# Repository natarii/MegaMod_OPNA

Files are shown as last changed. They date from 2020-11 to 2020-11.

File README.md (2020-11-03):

# OPNA MegaMod
This add-on board lets you play OPNA, OPN, and AY-3-8910 VGM files using your MegaGRRL Desktop.

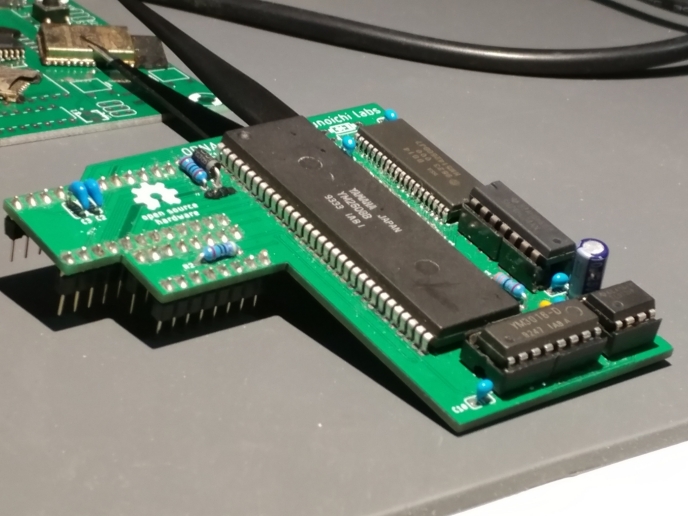
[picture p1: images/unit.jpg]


**This board is provided as an experimental add-on. Software support is working, but incomplete. Software support may improve in the future.**

**MegaGRRL Desktop Firmware v0.97dev or newer is required!** See [Firmware Releases](https://git.agiri.ninja/natalie/megagrrl/-/releases)

# Usage
1. Power off the MegaGRRL Desktop.
2. Remove the YM2612 and SN76489, and seat the addon board into their sockets.
3. Set all 4 DIP switches on the desktop board to OFF.
4. Power on. The presence of the OPNA board will be detected upon boot. Play an OPNA/OPN/AY-3-8910 VGM file.

# Bill of Materials
| Ref.Dsg. | Value | Note |
| --- | ----- | ---- |
| C1 | 10uF electrolytic |
| C2 | 2.7nF ceramic |
| C3 | 2.7nF ceramic |
| C4 | 68pF ceramic |
| C5 | 0.1uF ceramic |
| C6 | 0.1uF ceramic |
| C7 | 0.1uF ceramic |
| C8 | 0.1uF ceramic |
| C9 | 0.1uF ceramic |
| R1 | 33 ohm |
| R2 | 470 ohm |
| R3 | 1k ohm |
| RN1 | 10k bussed | Must be 9-pin bussed type |
| IC1 | YM2608 |
| IC2 | HM514260DJ | Tested with HM514260DJ. Other DRAMs may be compatible. Must be SOJ-40 footprint, 5V, 4Mbit (256Kx16), "fast page" type |
| IC3 | 74HC04 |
| IC4 | TL072 or SA5532 | Many opamps will work |
| IC5 | YM3016 |
| D1 | 1N5819 |
| Misc | 40 pins 0.1" machine pin header | 0.1" machine pin male-to-male headers, 40 pins total required. Must be machine pin type!!! |

All parts other than the DRAM at IC2 are THT.

# Assembly
1. Solder on the DRAM. Be careful to not short any pins underneath the IC
2. Solder on the remaining THT components. Pay attention that RN1 pin 1 goes towards the top of the board.
3. Solder on the pin headers (use MegaGRRL Desktop IC sockets for alignment)

# Gerber files
Gerbers for JLCPCB are in the `gerbers/` directory.

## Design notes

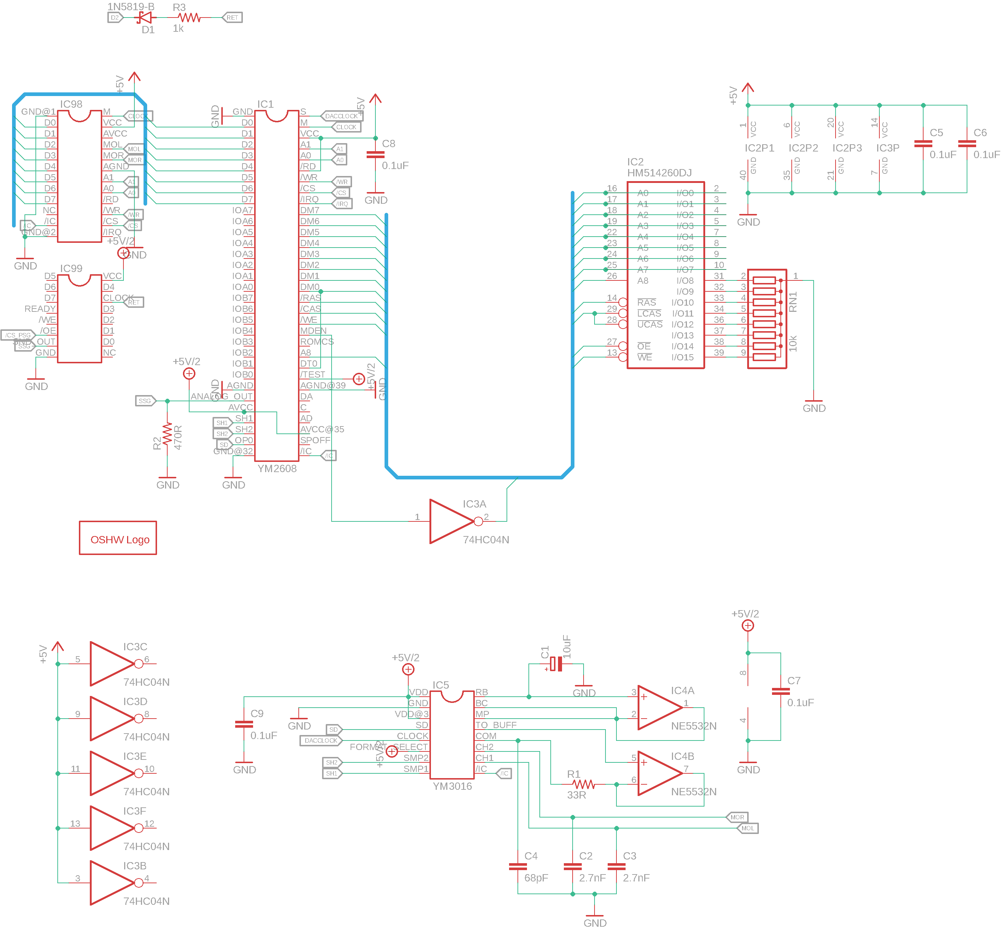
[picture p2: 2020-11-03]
images/sch.png

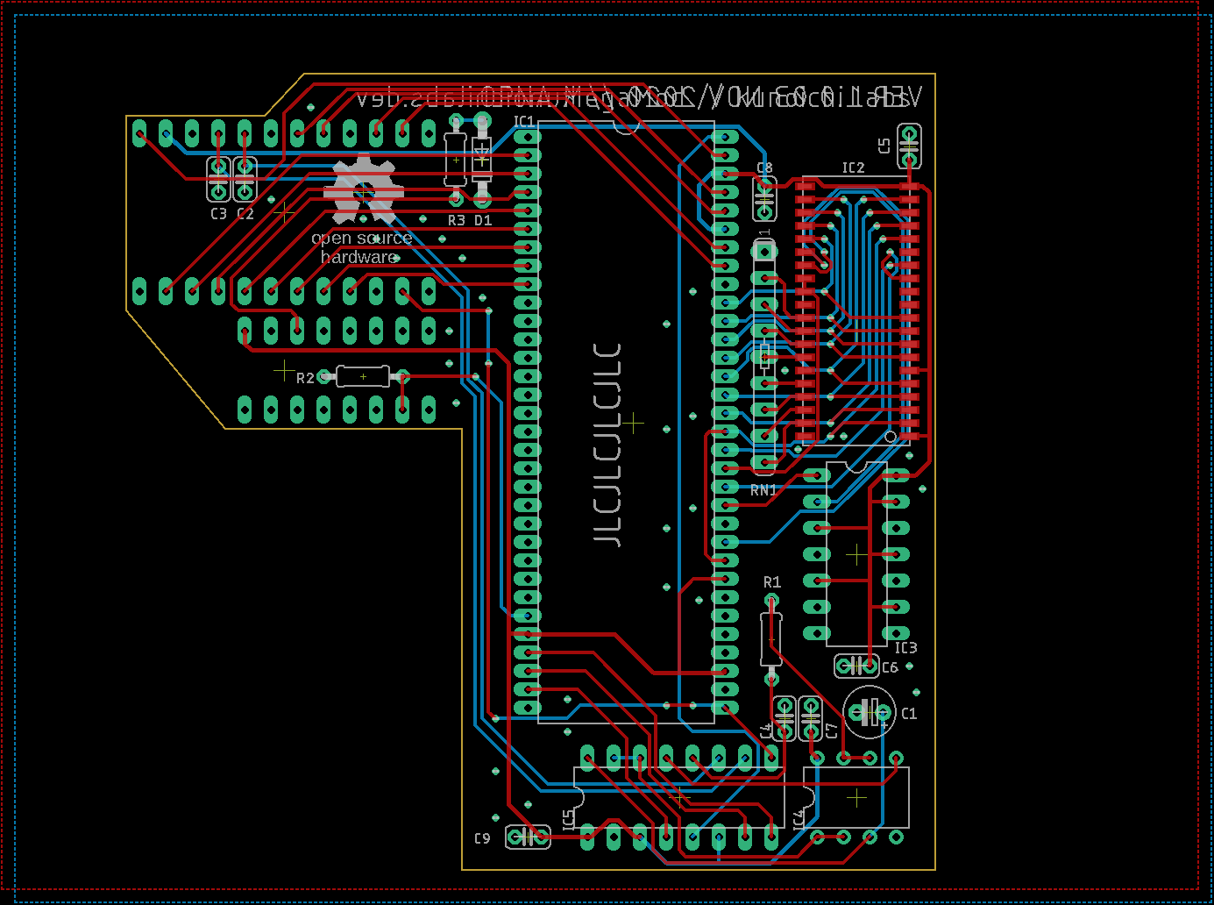
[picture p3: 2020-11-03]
images/pcb.png

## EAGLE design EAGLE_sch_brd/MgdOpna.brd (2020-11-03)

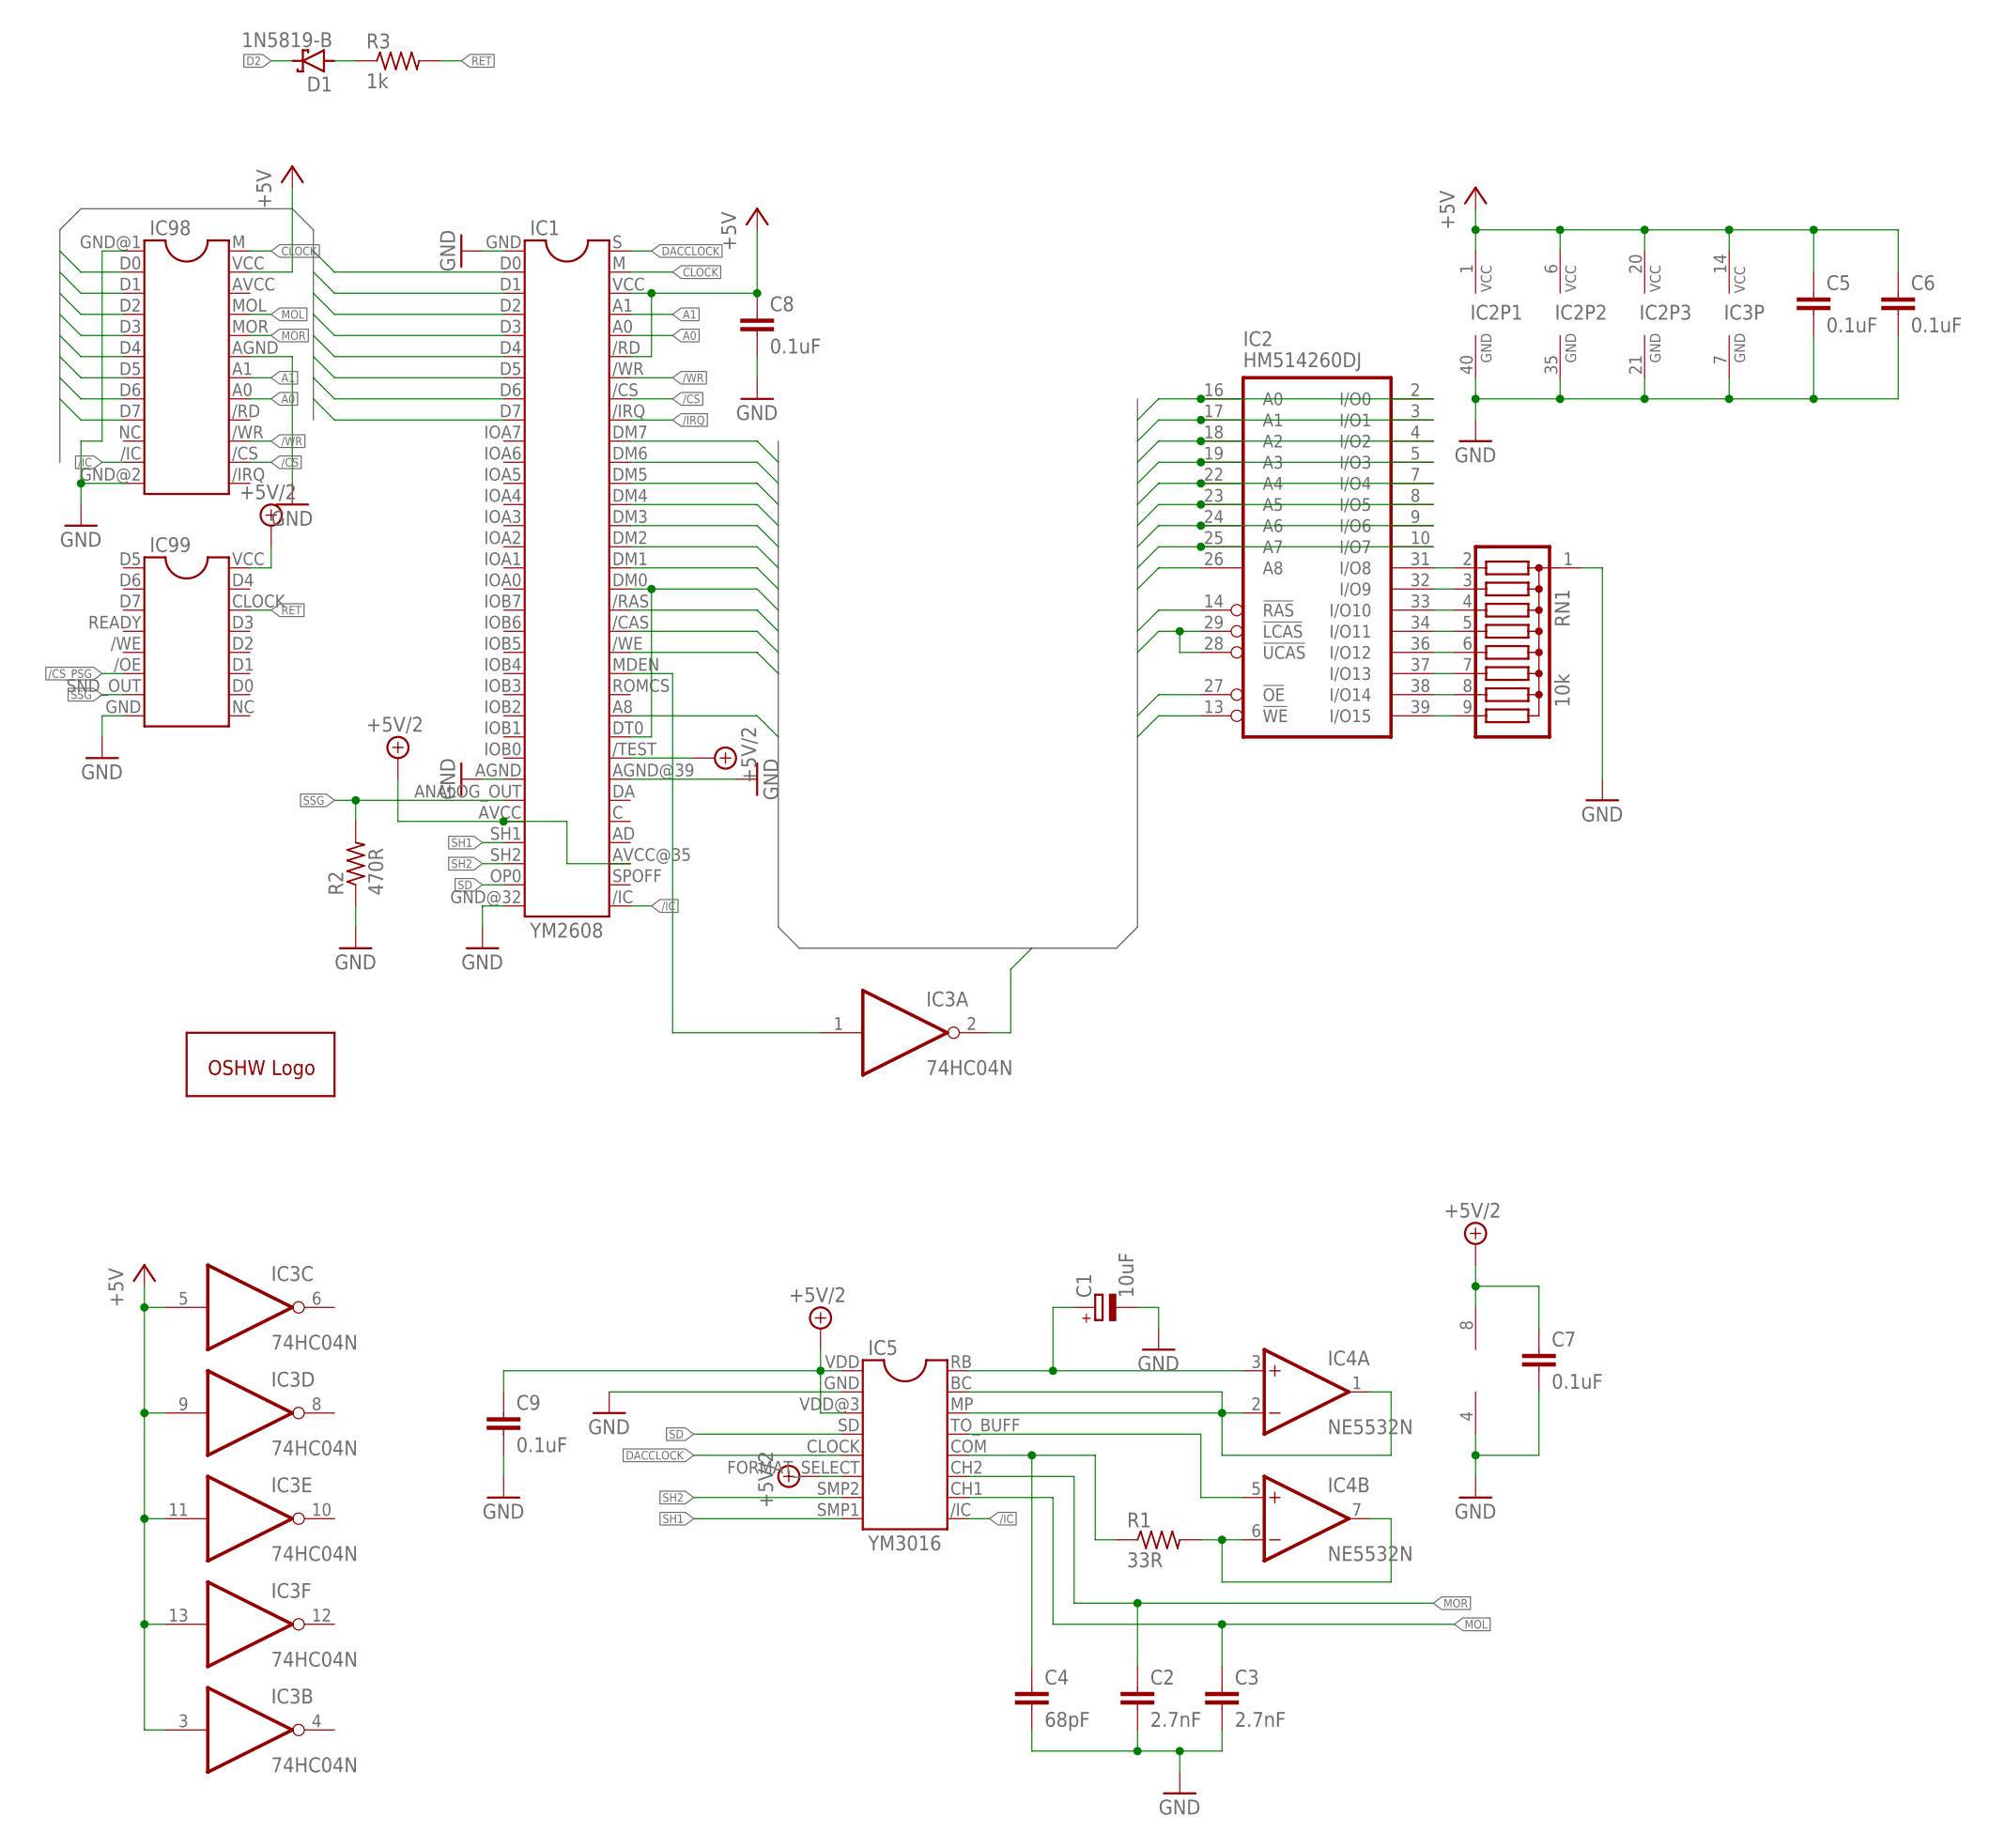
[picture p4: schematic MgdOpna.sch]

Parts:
C1: 10uF; E2,5-5
C2, C3: 2.7nF; C025-024X044
C4: 68pF; C025-024X044
C5, C6, C7, C8, C9: 0.1uF; C025-024X044
D1: 1N5819-B; DO41-7.6
GOLD_ORB_SM1: OSHWLOGOLOGO8MM; OSHW_8MM
IC1: YM2608
IC2: HM514260DJ; SOJ40-4
IC3: 74HC04N; DIL14
IC4: NE5532N; DIL08
IC5: YM3016
IC98: YM2612YM2612_NOSILK; YM2612_NOSILK
IC99: SN76489SN76489_NOSILK; SN76489_NOSILK
R1: 33R; 0204/7
R2: 470R; 0204/7
R3: 1k; 0204/7
RN1: 10k; SIL9

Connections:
+5V: C5.1, C6.1, C8.1, IC1./RD, IC1.VCC, IC2.1 (VCC), IC2.6 (VCC), IC2.20 (VCC), IC3.3 (I), IC3.5 (I), IC3.9 (I), IC3.11 (I), IC3.13 (I), IC3.14 (VCC), IC98.VCC
+5V/2: C7.1, C9.1, IC1./TEST, IC1.AVCC, IC1.AVCC@35 (AVCC), IC4.8 (V+), IC5.FORMAT_SELECT (6), IC5.VDD (1), IC5.VDD@3 (3), IC99.VCC
/CAS: IC1./CAS, IC2.28 (!UCAS), IC2.29 (!LCAS)
/CS: IC1./CS, IC98./CS
/CS_PSG: IC99./OE
/IC: IC1./IC, IC5./IC (9), IC98./IC
/IRQ: IC1./IRQ
/OE: IC2.27 (!OE), IC3.2 (O)
/RAS: IC1./RAS, IC2.14 (!RAS)
/WE: IC1./WE, IC2.13 (!WE)
/WR: IC1./WR, IC98./WR
A0: IC1.A0, IC98.A0
A1: IC1.A1, IC98.A1
A8: IC1.A8, IC2.26 (A8)
CLOCK: IC1.M, IC98.M
D0: IC1.D0, IC98.D0
D1: IC1.D1, IC98.D1
D2: D1.C, IC1.D2, IC98.D2
D3: IC1.D3, IC98.D3
D4: IC1.D4, IC98.D4
D5: IC1.D5, IC98.D5
D6: IC1.D6, IC98.D6
D7: IC1.D7, IC98.D7
DACCLOCK: IC1.S, IC5.CLOCK (5)
DM0: IC1.DM0, IC1.DT0 (DTO), IC2.2 (I/O0), IC2.16 (A0)
DM1: IC1.DM1, IC2.3 (I/O1), IC2.17 (A1)
DM2: IC1.DM2, IC2.4 (I/O2), IC2.18 (A2)
DM3: IC1.DM3, IC2.5 (I/O3), IC2.19 (A3)
DM4: IC1.DM4, IC2.7 (I/O4), IC2.22 (A4)
DM5: IC1.DM5, IC2.8 (I/O5), IC2.23 (A5)
DM6: IC1.DM6, IC2.9 (I/O6), IC2.24 (A6)
DM7: IC1.DM7, IC2.10 (I/O7), IC2.25 (A7)
GND: C1.-, C2.2, C3.2, C4.2, C5.2, C6.2, C7.2, C8.2, C9.2, IC1.AGND, IC1.AGND@39 (AGND), IC1.GND, IC1.GND@32 (GND), IC2.21 (GND), IC2.35 (GND), IC2.40 (GND), IC3.7 (GND), IC4.4 (V-), IC5.GND (2), IC98.AGND, IC98.GND@1 (GND), IC98.GND@2 (GND), IC99.GND, R2.1, RN1.1
MOL: C3.1, IC5.CH1 (10), IC98.MOL
MOR: C2.1, IC5.CH2 (11), IC98.MOR
unnamed: IC2.31 (I/O8), RN1.2
unnamed: IC2.32 (I/O9), RN1.3
unnamed: IC2.33 (I/O10), RN1.4
unnamed: IC2.34 (I/O11), RN1.5
unnamed: IC2.36 (I/O12), RN1.6
unnamed: IC2.37 (I/O13), RN1.7
unnamed: IC2.38 (I/O14), RN1.8
unnamed: IC2.39 (I/O15), RN1.9
unnamed: D1.A, R3.1
unnamed: IC1.MDEN, IC3.1 (I)
unnamed: C1.+, IC4.3 (+IN), IC5.RB (16)
unnamed: IC4.1 (OUT), IC4.2 (-IN), IC5.BC (15), IC5.MP (14)
unnamed: IC4.5 (+IN), IC5.TO_BUFF (13)
unnamed: IC4.6 (-IN), IC4.7 (OUT), R1.2
unnamed: C4.1, IC5.COM (12), R1.1
RET: IC99.CLOCK, R3.2
SD: IC1.OP0, IC5.SD (4)
SH1: IC1.SH1, IC5.SMP1 (8)
SH2: IC1.SH2, IC5.SMP2 (7)
SSG: IC1.ANALOG_OUT, IC99.SND_OUT, R2.2

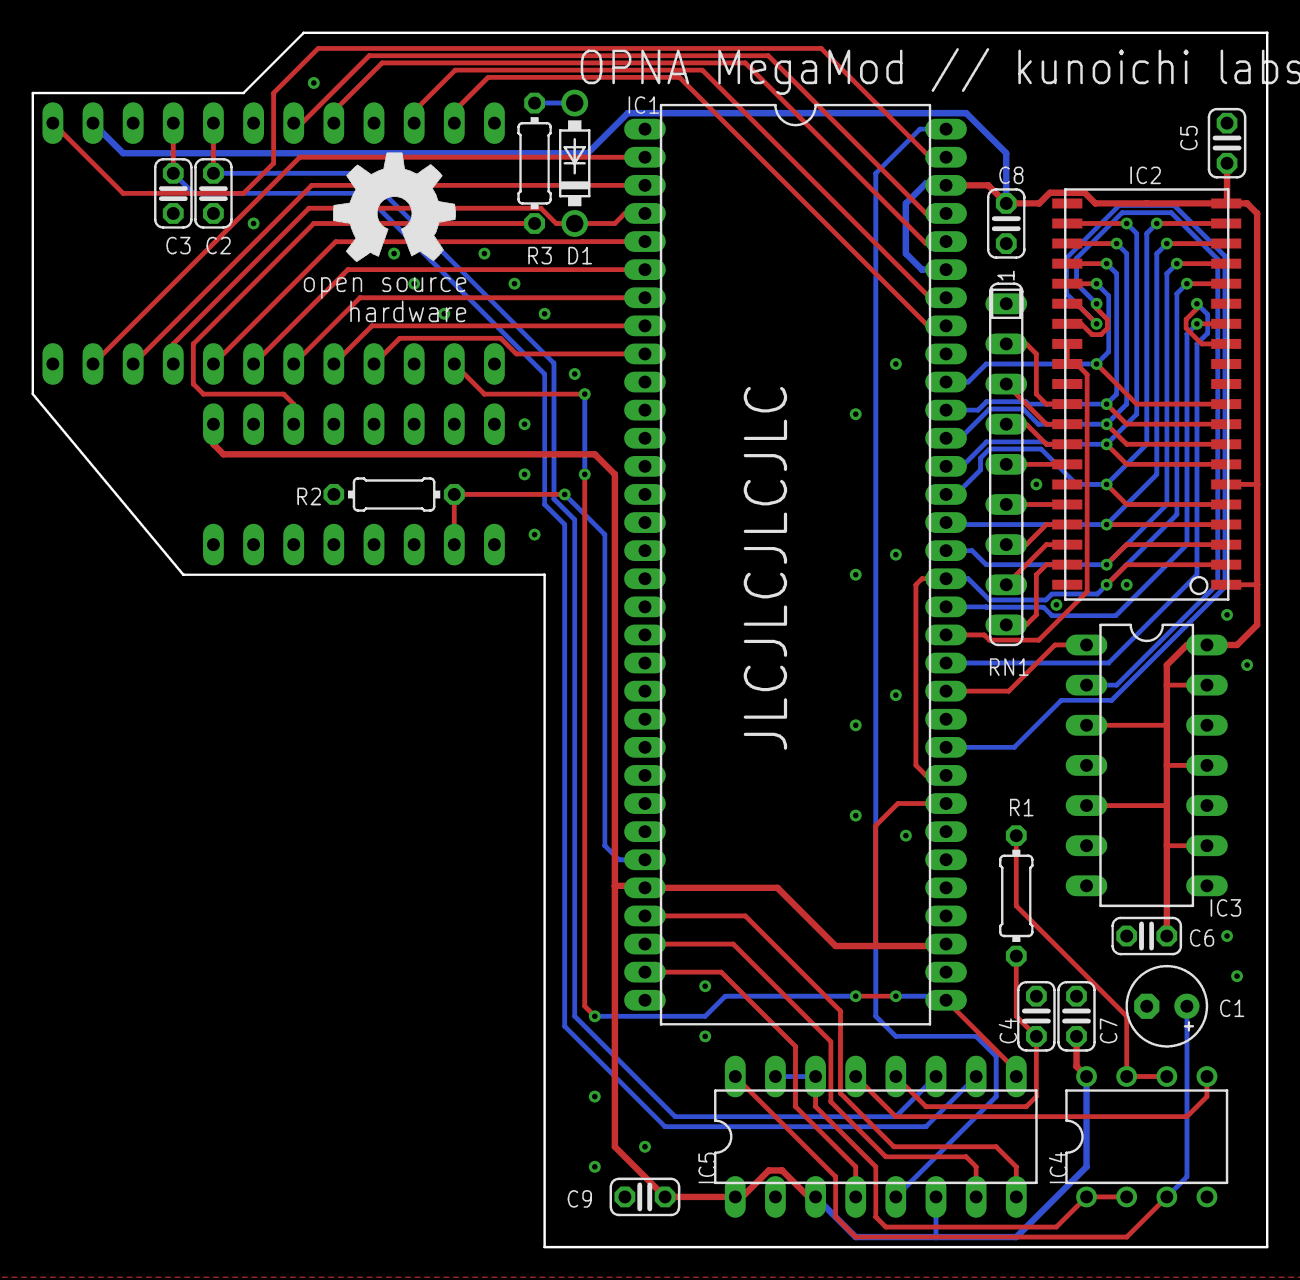
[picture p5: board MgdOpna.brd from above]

Board: 2 copper layers, 78.1 x 76.8 mm, 22 parts (0 on the bottom side), 53 nets.
